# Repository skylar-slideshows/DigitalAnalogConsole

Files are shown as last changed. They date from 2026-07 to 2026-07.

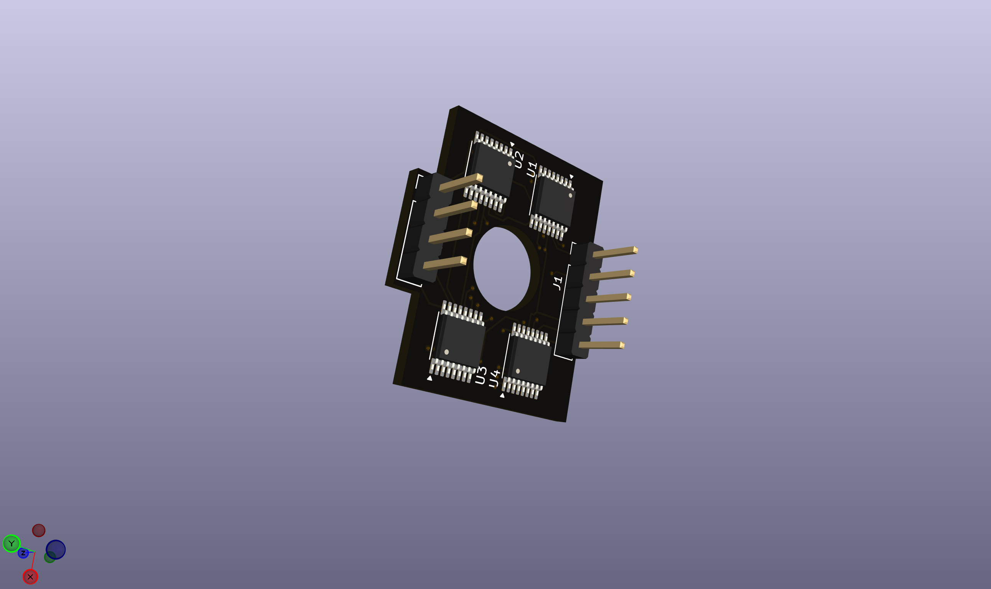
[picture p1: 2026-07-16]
PCB/led_ring_knob/3D2.png

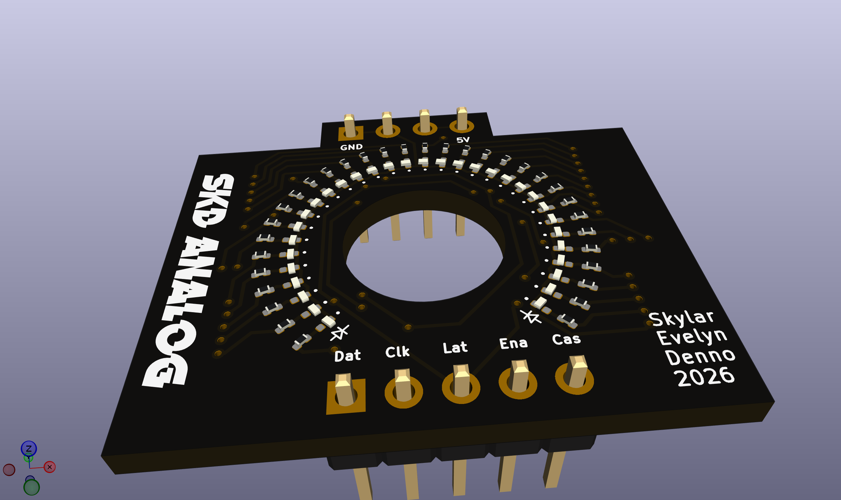
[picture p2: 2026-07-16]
PCB/led_ring_knob/3D1.png

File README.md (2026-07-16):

Skylar - Digital/Analog Music Mixing Console / Gear
A music mixing console with a fully analog audio signal path (no DSP), managed by a digital control system.

The problem to fix
Historically, music recording studios relied on analog audio processing equipment. While digital signal processing has largely replaced it, many professional audio engineers still prefer analog hardware for its perceived superior sound quality. However, analog equipment lacks instant recall, requiring engineers to manually reset knobs and controls between projects. Since these knobs control actual resistances/potentiometers in the signal path, they need to be physically moved to the right place. In today's fast-paced production environment, where multiple sessions may be completed in a single day, this process can be time-consuming and impractical.

Proposal
My proposal is to design a set of basic audio engineering analog sound processors (an EQualizer, a dynamic range compressor, and volume control) with a digital system that uses “voltage controlled resistors” to allow recall to be handled by a microprocessor, making it instant. Instead of having moving knobs that are physical resistors, the knobs will only be digital rotary encoders for which a microcontroller calculates their relative position. The microcontroller then uses a control voltage to set resistors in the analog signal path to the value that a real knob in that position would be, making the signal path exactly the same “to the audio.” This would also allow the microprocessor to automate and adjust many parameters at once, which is another limitation with analog audio equipment. These three basic devices can be combined into one digitally controlled, analog “channel strip” that handles one layer of audio in the mix of a song. Many of these channels side by side, with a master section that combines all the signals, makes an audio console. This kind of technology is present in some standalone pieces of audio equipment, as well as parts of some synthesizers, but it has never been done at such a large scale.

Technical explanation
The “knobs” in our device (actually rotary encoders), send a digital signal with their relative position. To “scan” all the digital encoder “knobs” positions’, a microcontroller can be multiplexed to them, cycling through looking at all the knobs’ data outputs several times per second, meaning a few GPIO pins can be used to interface with many knobs. 

The microcontroller then calculates the value that a real potentiometer (based on its value and taper - linear? Log? anti-log?) would have in that same positon.

To make voltage controlled resistors that actually supply this resistance in the analog audio path, there are many approaches. A FET transistor has a “triode” or “OHMIC” region between when it is on and off, of high resistance, which varies by its gate voltage. As long as we stay away from the very edges of this region, the behavior is approximately linear (moreso on JFETs - Junction Field Effect Transistors) making them suitable for audio.
Another way is with OTAs (operational transconductance amplifiers), which are voltage controlled current sources. Since resistors themselves turn voltage into current, OTAs are essentially like resistors for our purpose.

For a non-continuous controllable resistor, we can use a network of many resistors in series and parallel, with transistors (electronic switches) between them to connect them in various ways that can produce an equivalent resistance through the entire network of essentially any value we want. There are premade chips for this. (resistor ladders)

We need to make sure that however we control the components, it does not get in the way of making a highly linear (low harmonic distortion), high fidelity (flat frequency response between 20Hz and 20kHz) audio path - i.e. making a good sounding piece of equipment that doesn’t distort the sound.

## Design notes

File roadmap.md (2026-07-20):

Digital/Analog mixing console:

## More developed idea
- Clear goal/pathway to developing a finished project
- Covers areas of analog and digital electronics, some control systems, and software

## Room for development (what can 6 people spend several months on if this idea is already developed)

### Analog

#### Volume sliders
Voltage-controlled amplifiers: 
2x per channel, 32x total (16 channels)
  
#### Power Supply
+/-18V rails through a linear power supply for clean signal (min. ~15W) 
+3.3V clean reference for DACs in digital circuit (\~1W) 
+3.3V rail for digital electronics (\~20W) (isolated from clean ref. to prevent noise) 
+5V rail for LEDs 

#### Equalizer
State variable filter 
Control voltage comes from amplified DAC signal 
Op amp circuit to amplify DAC signal to control voltage for OTAs 

#### Pan
L/R VCAs for each channel 
Control voltage(s) come from DAC signal  

#### Toggle buttons (Mute/Solo)
Debounce circuit 
Button LED 
Software toggle to allow software control 

#### Insert points
Between each channel and the summing bus (pre- or post-fader option) 

#### Sends
Auxiliary busses

#### Master Section
Summing bus
AUX returns
Large screen
Master bus insert

#### Compressor

### Digital

#### Faders (motor-driven slide potentiometers)
Read by ADC on the chip 
Abstracted into something servo-like 
VCAs are controlled from software based on reading of faders 

#### EQ/Pan knobs
Rotary encoders 
LED ring 

#### Screens

### Software
(generally controlling all of the digital parts)

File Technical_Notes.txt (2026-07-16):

A mixing console is just a bunch of channels of signal processors, and a summing amplifier.
The three main tools audio engineers need on a mixing console are:
Volume (slider/fader to turn things up and down)
Equalizer (controllable frequency/bandwidth filters + summing with the original signal)
Dynamic compression (automatically turn loud parts of audio down but leave quiet audio untouched)

Volume/pan - will implement with VCA, controlled by a motorized fader being read by a microcontroller.

EQ - will implement with OTAs, voltage controllable "resistance" (current scaling) - fully parametric, can use OTAs to control freq, bw, and gain, see the analog design folder: EQ for spice sims.

Compression - will implement with VCA, the control voltage envelope generated by the microcontroller possibly. (otherwise will need OTAs for some params)

Digital control - microcontroller (STM32G474), rotary encoders (EC11), faders/slide potentiometers read by a ADC, screens, LEDs to show position of knobs (shift registers), outboard DACs (on SPI bus) to generate the control voltages.

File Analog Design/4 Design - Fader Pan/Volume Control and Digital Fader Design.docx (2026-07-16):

Volume Control and Digital Fader Design

We want a device that allows the volume of channels to be controlled with a slide potentiometer (Fader). Instead of a traditional analog design with the audio signal running through the fader’s resistance strip itself, we use a microcontroller to read the position of the fader through its resistance. That microcontroller then addresses the VCA with a control voltage that produces the specified gain/atten.

This has the benefit of being instantly recallable and able to be saved and automated digitally.

Microcontroller for each bucket of 8 faders = RP2040. $1 per bucket

The ALPS RSA0N11M9 fader was chosen. It is motorized, touch sensitive, 10kOhm linear taper. 100mm long throw length. $26x8 = $208 per bucket

THAT 2181 is chosen for VCA. $6.5*16 = $104 per bucket

For line input receiver – TI INA2134 (stereo). $6x8 = $48 per bucket

Separate analog and [digital+controllers(pots,faders)] boards. They sit on top of each other (analog bottom)

PINS: (3+32+16)

Analog GND

+18V Power

-18V Power

VCA C1L

VCA C1R

VCA C2L

…

VCA C8R

Fader1 Voltage

Fader2 Voltage

…

Fader8 Voltage

Pan1 Voltage

Pan2Voltage

…

Pan8Voltage

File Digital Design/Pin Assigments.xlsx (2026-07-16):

FN | DESC | PROTO | PIN # | LABEL | CONN | STM32G4(74RET6)
KNOBS | 8 x MCP23017 - 40 rotary encoders | I2C 1 | PB8 | KNOB_I2C1_CL
 |  |  | PB7 | KNOB_I2C1_DA
BUTTONS | 1 x MCP23017 - 16 Buttons | I2C 2 | PC4 | BTNS_I2C2_CL
 |  |  | PF0 | BTNS_I2C2_DA
MASTER | Comm to master controller | I2C 3 | PC8 | MASTER_I2C3_CL
 |  |  | PC9 | MASTER_I2C3_DA
CV | Output Control Voltage to devices DAC80508M | SPI 1 Transmit ONLY | PA5 | CV_SPI1_CL
 |  |  | PA7 | CV_SPI1_MOSI
DISP_1_2 | Displays 1 and 2 | SPI 2 Transmit ONLY | PF1 | DISP12_SPI2_CL
 |  |  | PB15 | DISP12_SPI2_MOSI
DISP_3_4 | Displays 3 and 4 | SPI 3 Transmit ONLY | PC10 | DISP34_SPI3_CL
 |  |  | PB5 | DISP34_SPI3_MOSI
LEDS | 74HCT595 Clocks | GPIO | PC13 | LED_CL
 | 74HCT595 Data | GPIO | PC2 | LED_DA
 | 74HCT595 Latches | GPIO | PC3 | LED_LATCH
 | 74HCT595 Output enable (brightness) | TIM1 PWM 2khz ch1 | PC0 | LED_BRIGHT_PWM
DISP BACKLIGHT | Display backlight control | TIM1 PWM 2khz ch2 | PC1 | DISP_BRIGHT_PWM
RESET | Active low (built in pull up) |  | PG10 | NRST
PRGM | Programming firmware to the chip | SWD | PA13 | SWDIO
 |  |  | PA14 | SWCLK
VSS_Analog | Clean gnd ref for adcs (analog gnd plane) |  | VSSA | VSSA
VDD_Analog | Clean 3v3 ref for adcs (filter 3v3B23:B33 |  | VDDA | VDDA
V_Battery | Tie to 3v3 VCC regular (no battery) |  | VBAT | VBAT
V_reference + | Tie to clean 3v3 same as VDDA |  | VREF+ | VREF+
FADER | Read position of slide pots thru built in adcs | ADC 1 CH 1-4 | PA0 | FADER1_ADC
 |  |  | PA1 | FADER2_ADC
 |  |  | PA2 | FADER3_ADC
 |  |  | PA3 | FADER4_ADC
FADER TOUCH | Sense if faders are being touched (capacitive sampling TTP224) | GPIO INPUT | PB11 | FADER1_TOUCH
 |  |  | PB12 | FADER2_TOUCH
 |  |  | PB13 | FADER3_TOUCH
 |  |  | PB14 | FADER4_TOUCH
FADER MOTOR | Fader motor controller with PWM H bridges (DRV8833 x2) | TIM2 PWM 24khz ch1/2 | PA15 | FADER1_MOTOR1
 |  |  | PB3 | FADER1_MOTOR2
 |  | TIM3 PWM 24khz ch1/2 | PA6 | FADER2_MOTOR1
 |  |  | PA4 | FADER2_MOTOR2
 |  | TIM4 PWM 24khz ch1/2 | PA11 | FADER3_MOTOR1
 |  |  | PA12 | FADER3_MOTOR2
 |  | TIM5 PWM 24khz ch1/2 | PB2 | FADER4_MOTOR1
 |  |  | PC12 | FADER4_MOTOR2

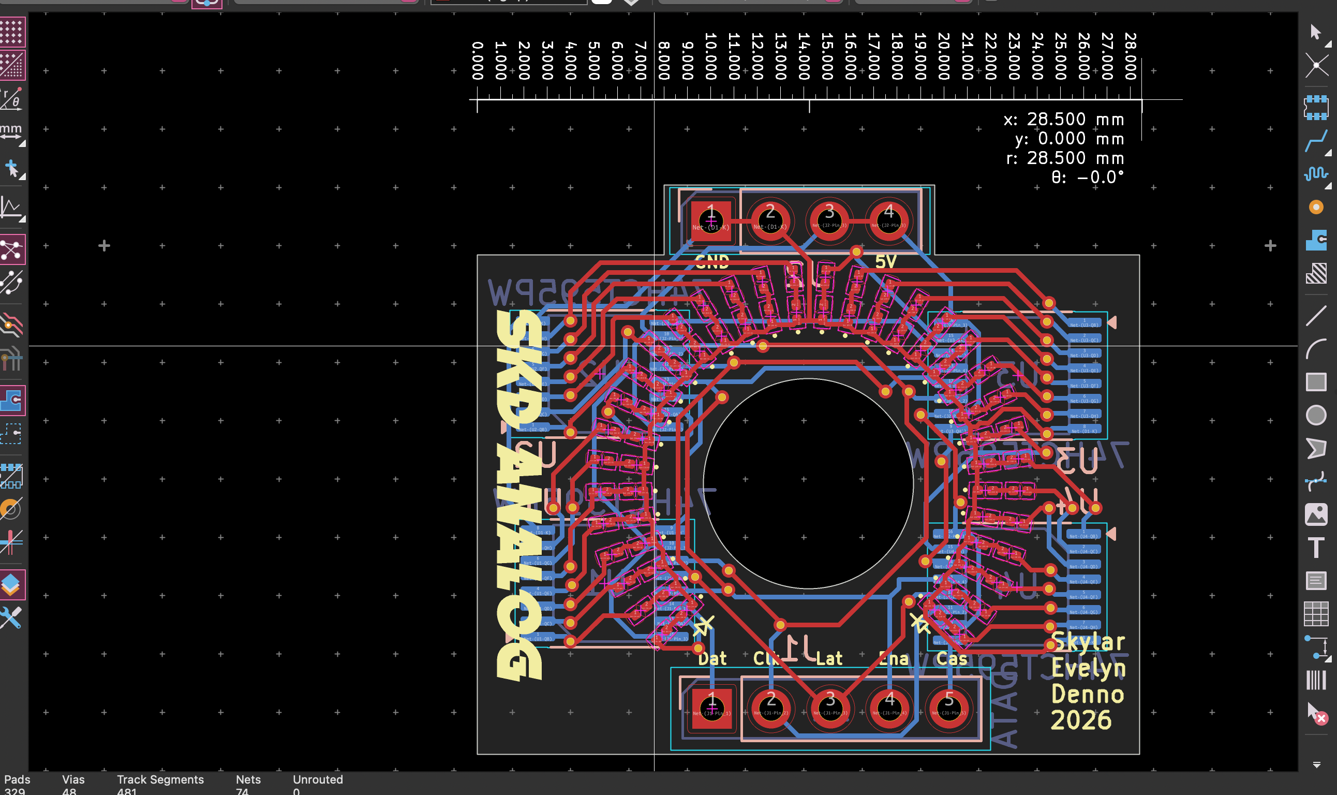
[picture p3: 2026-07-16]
PCB/led_ring_knob/layout.png

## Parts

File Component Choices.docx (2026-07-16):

DIGITAL

Controller – STM32G474

Addtl ADC - ADS1115

Addtl DAC – DAC80508M

?Use? I2C Multiplexer - TCA9548A

Op Amp Control Sigs - TL074

PHYSICAL

Fader – Alps RSA0N Slide 100mm Motorized, Touch sensitive (Clones)

Rotary Encoder – EC11 with switch (press knob), cap = sifam 11.5mm

LED Shift Register - 74HCT595 (4x per knob)

Button –

Laser Cutter – xTool M2

ANALOG

Op Amp – NE5532

Op Amp (Hifi) – OPA 2134

Line In – INA 2137

OTA – LM13700

VCA – THAT 2180B

Signal Switch - ADG1404

VU Meter – LM3916

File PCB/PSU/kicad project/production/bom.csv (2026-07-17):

Designator | Footprint | Quantity | Value | LCSC Part #
C1, C11, C12, C2, C3, C4 | CP_Radial_D18.0mm_P7.50mm | 6 | 4700u
C10, C14, C9 | 1206 | 3 | 100n
C13, C7, C8 | C_Rect_L24.0mm_W12.6mm_P22.50mm_MKT | 3 | 10u
C15 | 1206 | 1 | 10n
C16, C18, C20, C22 | CP_Radial_D12.5mm_P5.00mm | 4 | 1000u
C17, C19, C21, C23 | CP_Radial_D10.0mm_P5.00mm | 4 | 470u
C5, C6 | CP_Elec_6.3x5.4 | 2 | 10u
D1, D2, D3, D4 | D_DO-201AD_P15.24mm_Horizontal | 4 | 1N5404
D10, D11, D12, D13, D14, D15 | LED_Rectangular_W3.9mm_H1.8mm | 6 | LED
D5, D6 | Diode_Bridge_32.0x5.6x17.0mm_P10.0mm_P7.5mm | 2 | GBJ2510
D7, D8, D9 | D_SOD-123 | 3 | 1N4148
HS1, HS2, HS3 | HSINK_HSE-B20380-040H | 3 | Heatsink
J10 | TerminalBlock_Phoenix_MKDS-1,5-2-5.08_1x02_P5.08mm_Horizontal | 1 | SMPS_IN
J2 | TerminalBlock_Phoenix_MKDS-1,5-4-5.08_1x04_P5.08mm_Horizontal | 1 | OUT_ANLG
J3 | TerminalBlock_Phoenix_MKDS-1,5-2-5.08_1x02_P5.08mm_Horizontal | 1 | MAINS_IN
J4 | TerminalBlock_Phoenix_MKDS-1,5-4-5.08_1x04_P5.08mm_Horizontal | 1 | Screw_Terminal_01x04
J5 | TerminalBlock_Phoenix_MKDS-1,5-4_1x04_P5.00mm_Horizontal | 1 | T1_SEC
J6 | PinHeader_1x03_P2.54mm_Vertical | 1 | GND_LIFT
J7 | PinHeader_1x02_P2.54mm_Vertical | 1 | FAN1_12V
J8 | PinHeader_1x02_P2.54mm_Vertical | 1 | FAN2_12V
J9 | TerminalBlock_Phoenix_MKDS-1,5-4-5.08_1x04_P5.08mm_Horizontal | 1 | OUT_DIGI
L1, L2, L3, L4 | L_Vishay_IHLP-5050 | 4 | 4.7u
R1, R2, R3 | R_Axial_DIN0414_L11.9mm_D4.5mm_P20.32mm_Horizontal | 3 | 1k
R10, R9 | 1206 | 2 | 1.5k
R11, R12 | 1206 | 2 | 100
R13 | 1206 | 1 | 330
R14 | 1206 | 1 | 820
R15 | 1206 | 1 | 56k
R16, R17, R18, R19 | R_Axial_DIN0207_L6.3mm_D2.5mm_P10.16mm_Horizontal | 4 | 0.33R
R4 | 0805 | 1 | 10
R5, R6 | 1206 | 2 | 4.7k
R7, R8 | 1206 | 2 | 360
SW2 | SW_V80214MS02Q | 1 | V80212MS02Q
TH1 | C_Disc_D12.5mm_W5.0mm_P7.50mm | 1 | MF72-010D9
TR2 | AMGIS L01-63XX | 1 | Amgis L01-6320
U1 | TO-220-3_Vertical | 1 | LM317AT/NOPB
U2 | TO-220-3_Vertical | 1 | LM337T/NOPB
U3 | TO-220-3_Vertical | 1 | LD1117V33C
U5 | Converter_DCDC_XP_POWER_JTDxxxxxxx_THT | 1 | 3v3 Mornsun URB4803LD-20WR3
U6 | MeanWell NID100 | 1 | MeanWell NID-100-5
U7 | Converter_DCDC_XP_POWER_JTDxxxxxxx_THT | 1 | 12v Mornsun URB2412LD-30WR3

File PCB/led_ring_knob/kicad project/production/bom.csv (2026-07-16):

Designator | Footprint | Quantity | Value | LCSC Part #
D1, D10, D11, D12, D13, D14, D15, D16, D17, D18, D19, D2, D20, D21, D22, D23, D24, D25, D26, D27, D28, D29, D3, D30, D31, D32, D4, D5, D6, D7, D8, D9 | 0201 | 32 | CSP0603AN101-WP30300563001-3T
J1 | PinHeader_1x05_P2.54mm_Vertical | 1 | DATA
J2 | PinHeader_1x04_P2.54mm_Vertical | 1 | POW
R1, R10, R11, R12, R13, R14, R15, R16, R17, R18, R19, R2, R20, R21, R22, R23, R24, R25, R26, R27, R28, R29, R3, R30, R31, R32, R4, R5, R6, R7, R8, R9 | 0201 | 32 | 330
U1, U2, U3, U4 | TSSOP-16_4.4x5mm_P0.65mm | 4 | 74HCT595PW

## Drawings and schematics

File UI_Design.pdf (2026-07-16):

## SEND

## Aux 1 (press enable)

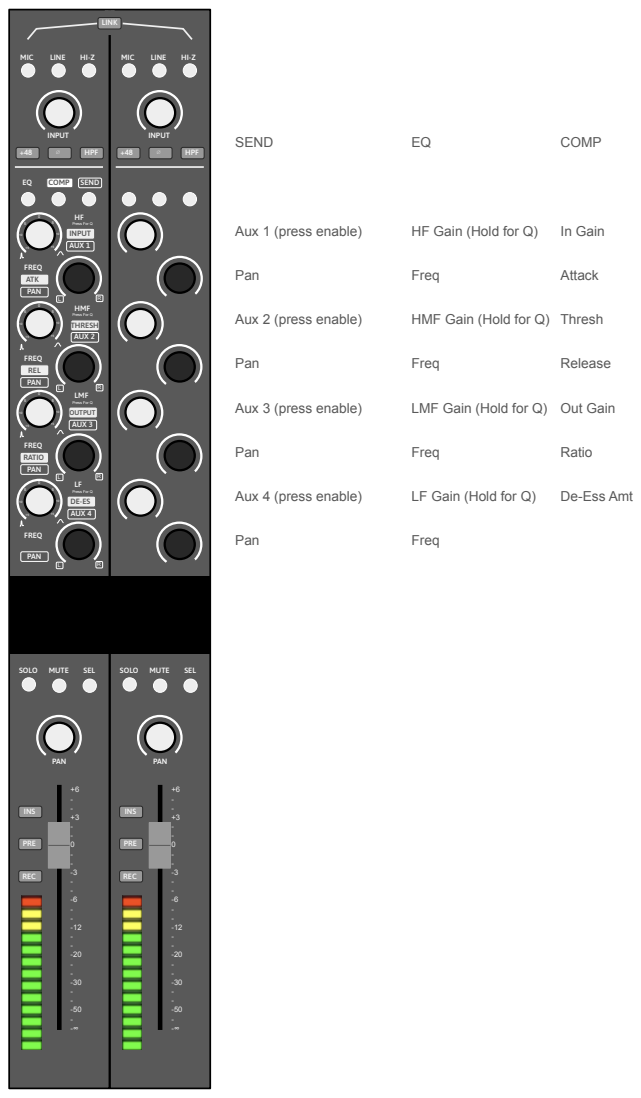
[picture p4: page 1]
SOLO; MUTE; SEL; PAN; COMP; SEND; MIC; LINE; HPF; INS; PRE; REC; LINK; INPUT; Pan; Freq; In Gain; Attack; Thresh; Release; Out Gain; Ratio; FREQ; Press For Q; HMF; LMF; ATK; THRESH; REL; OUTPUT; RATIO; AUX 1; AUX 2; AUX 3; AUX 4

HF Gain (Hold for Q)

Aux 2 (press enable)

HMF Gain (Hold for Q)

Aux 3 (press enable)

LMF Gain (Hold for Q)

LF Gain (Hold for Q)

Aux 4 (press enable)

De-Ess Amt

## AUX INPUTS

1 2

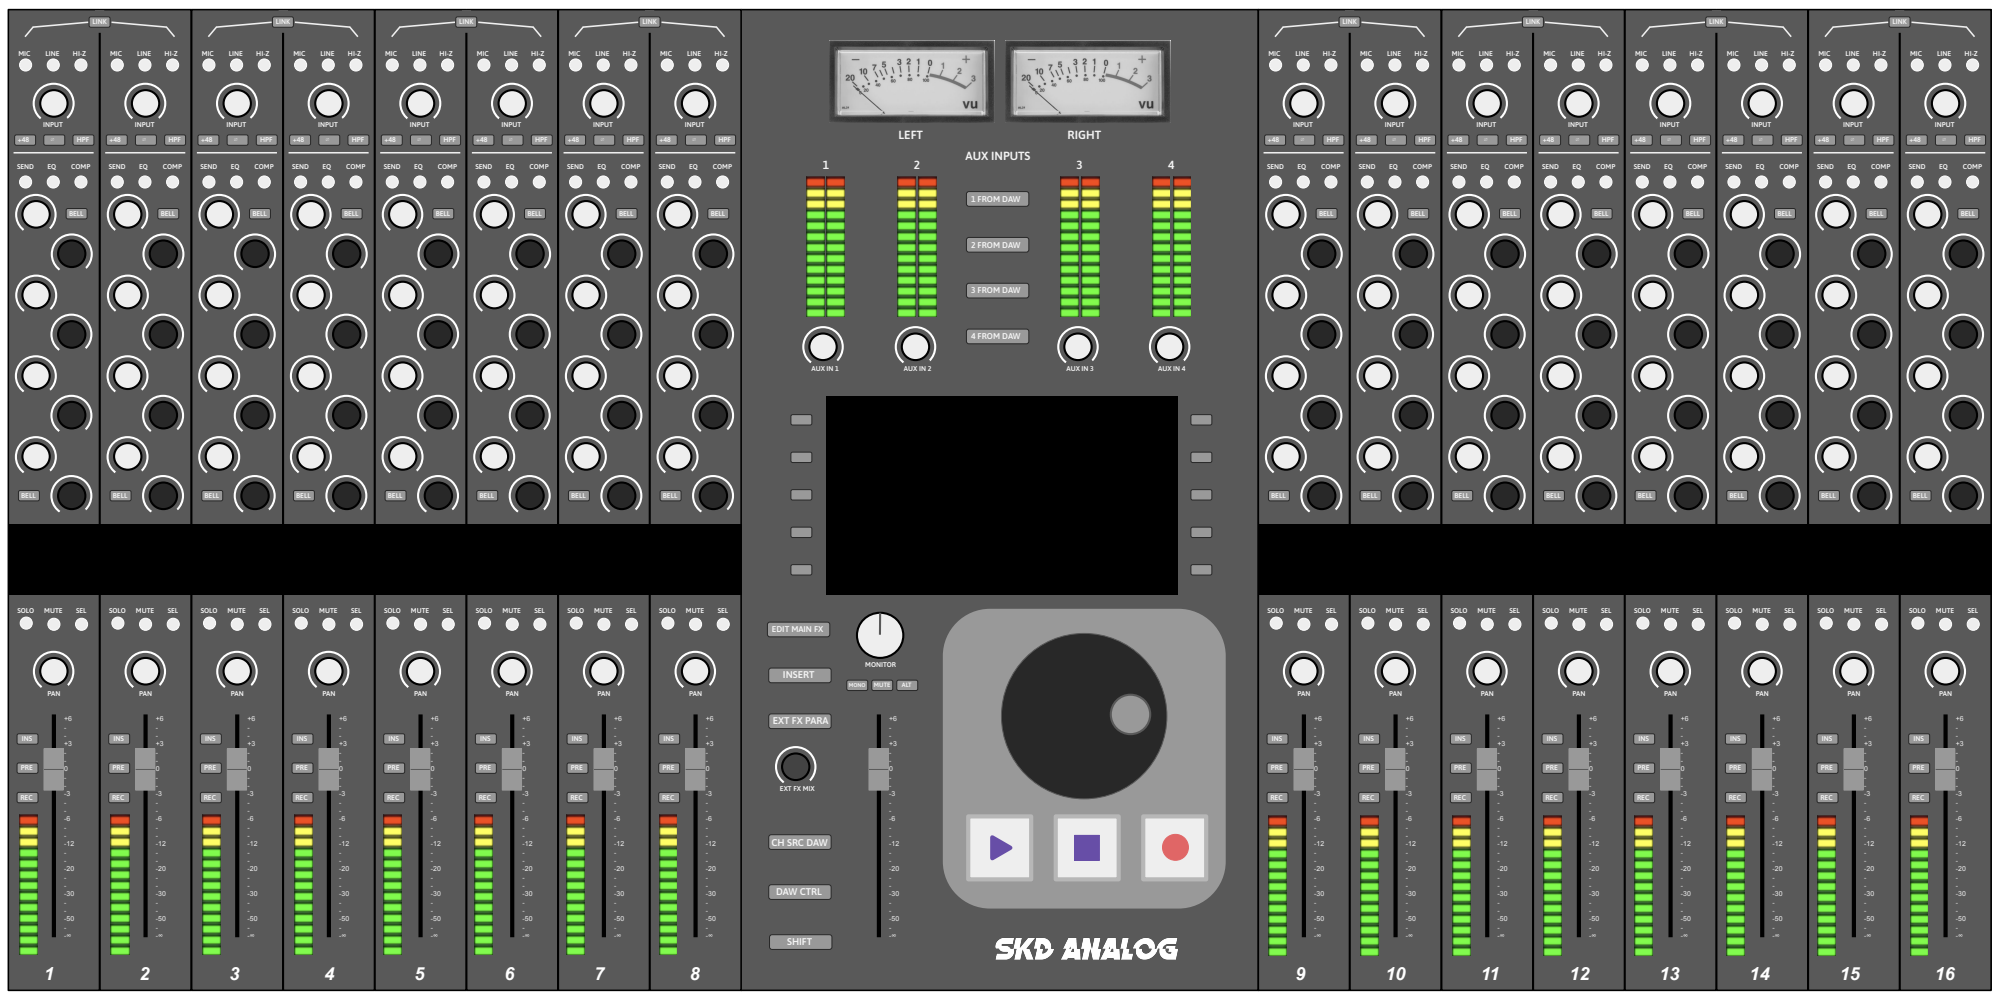
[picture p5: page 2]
SOLO; MUTE; SEL; PAN; SEND; COMP; MIC; LINE; BELL; HPF; INS; PRE; REC; LINK; INPUT; AUX IN 1; AUX IN 2; DAW CTRL; SHIFT; 1 FROM DAW; 2 FROM DAW; 3 FROM DAW; 4 FROM DAW; AUX IN 3; AUX IN 4; LEFT; RIGHT; INSERT; MONITOR; MONO; ALT

EDIT MAIN FX

EXT FX PARA

EXT FX MIX

CH SRC DAW

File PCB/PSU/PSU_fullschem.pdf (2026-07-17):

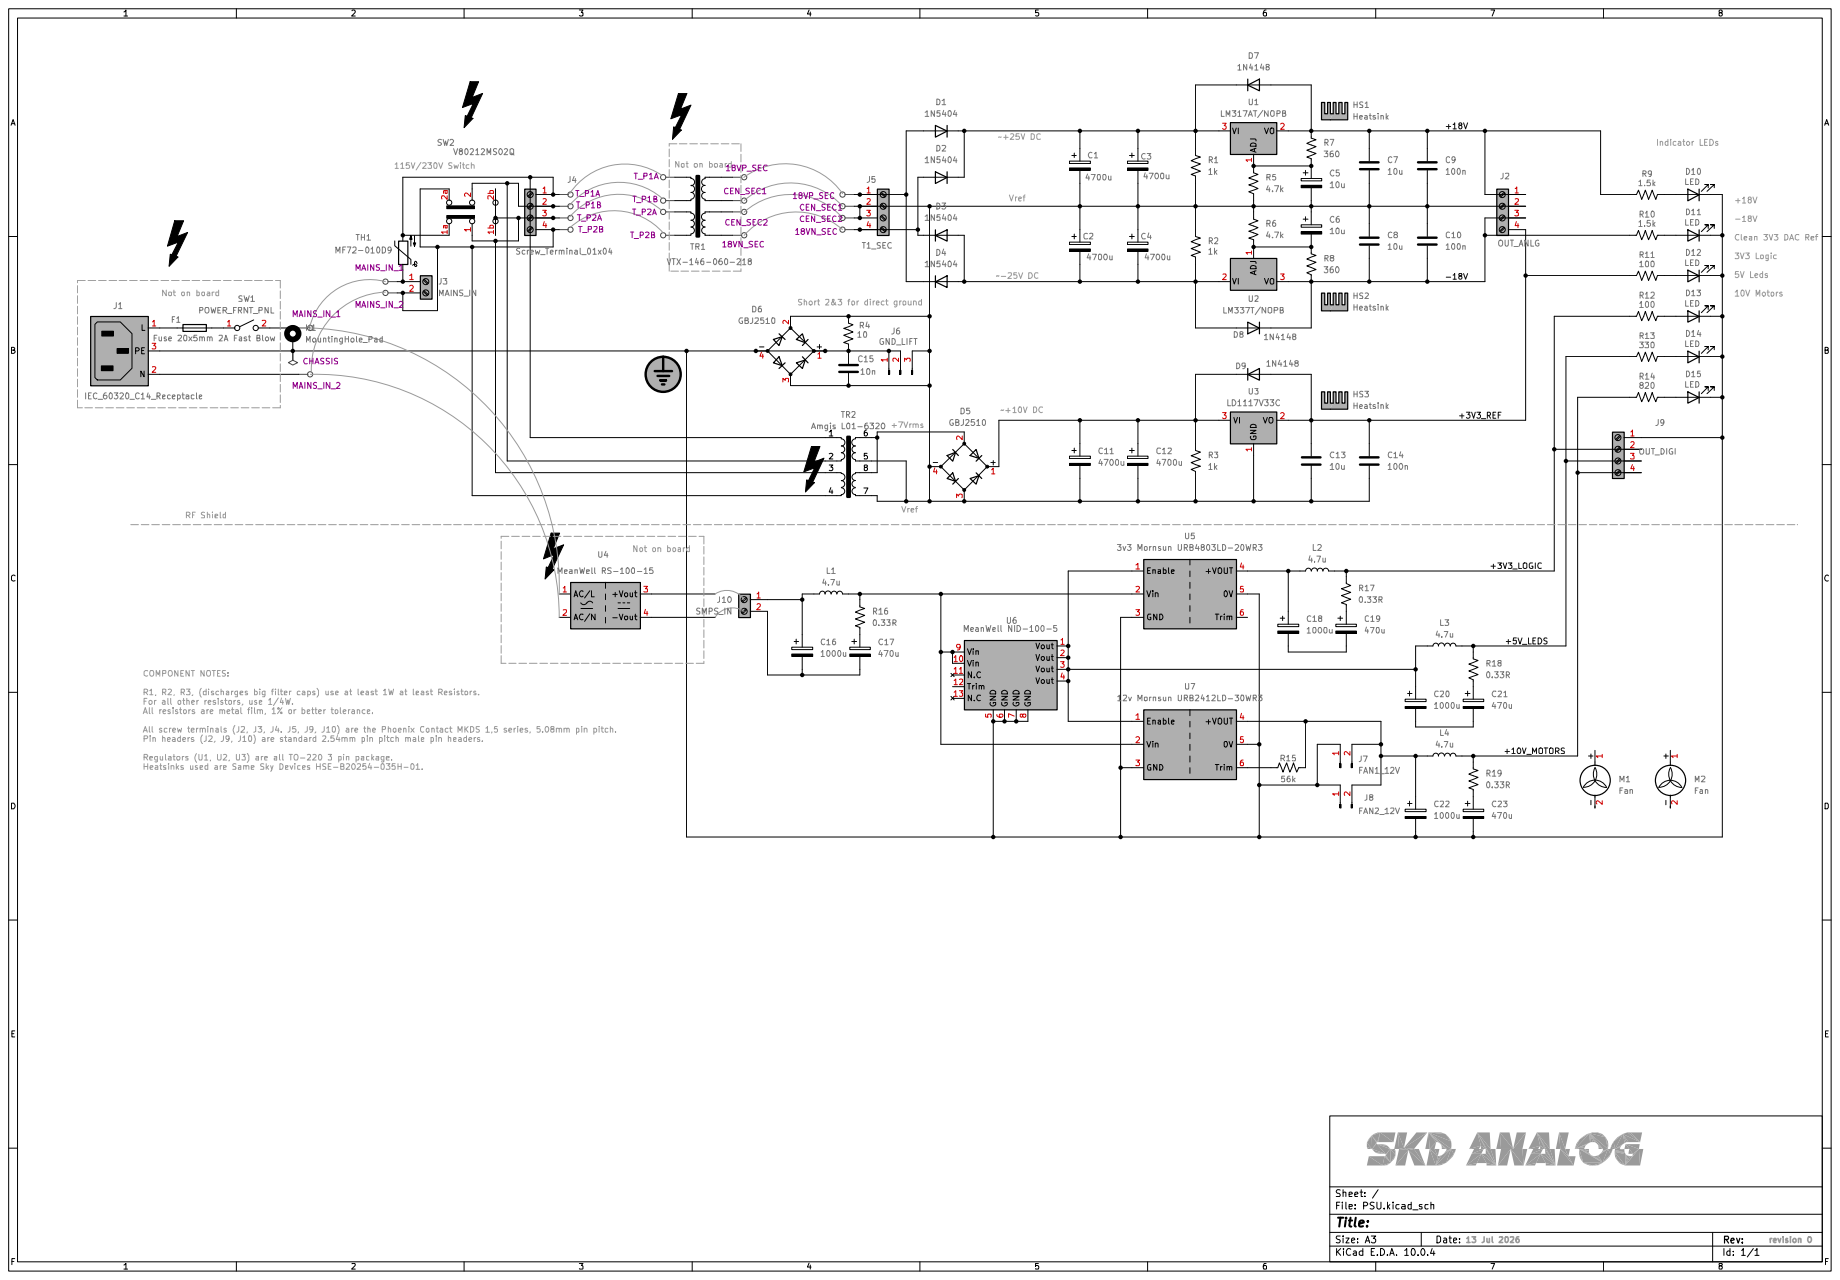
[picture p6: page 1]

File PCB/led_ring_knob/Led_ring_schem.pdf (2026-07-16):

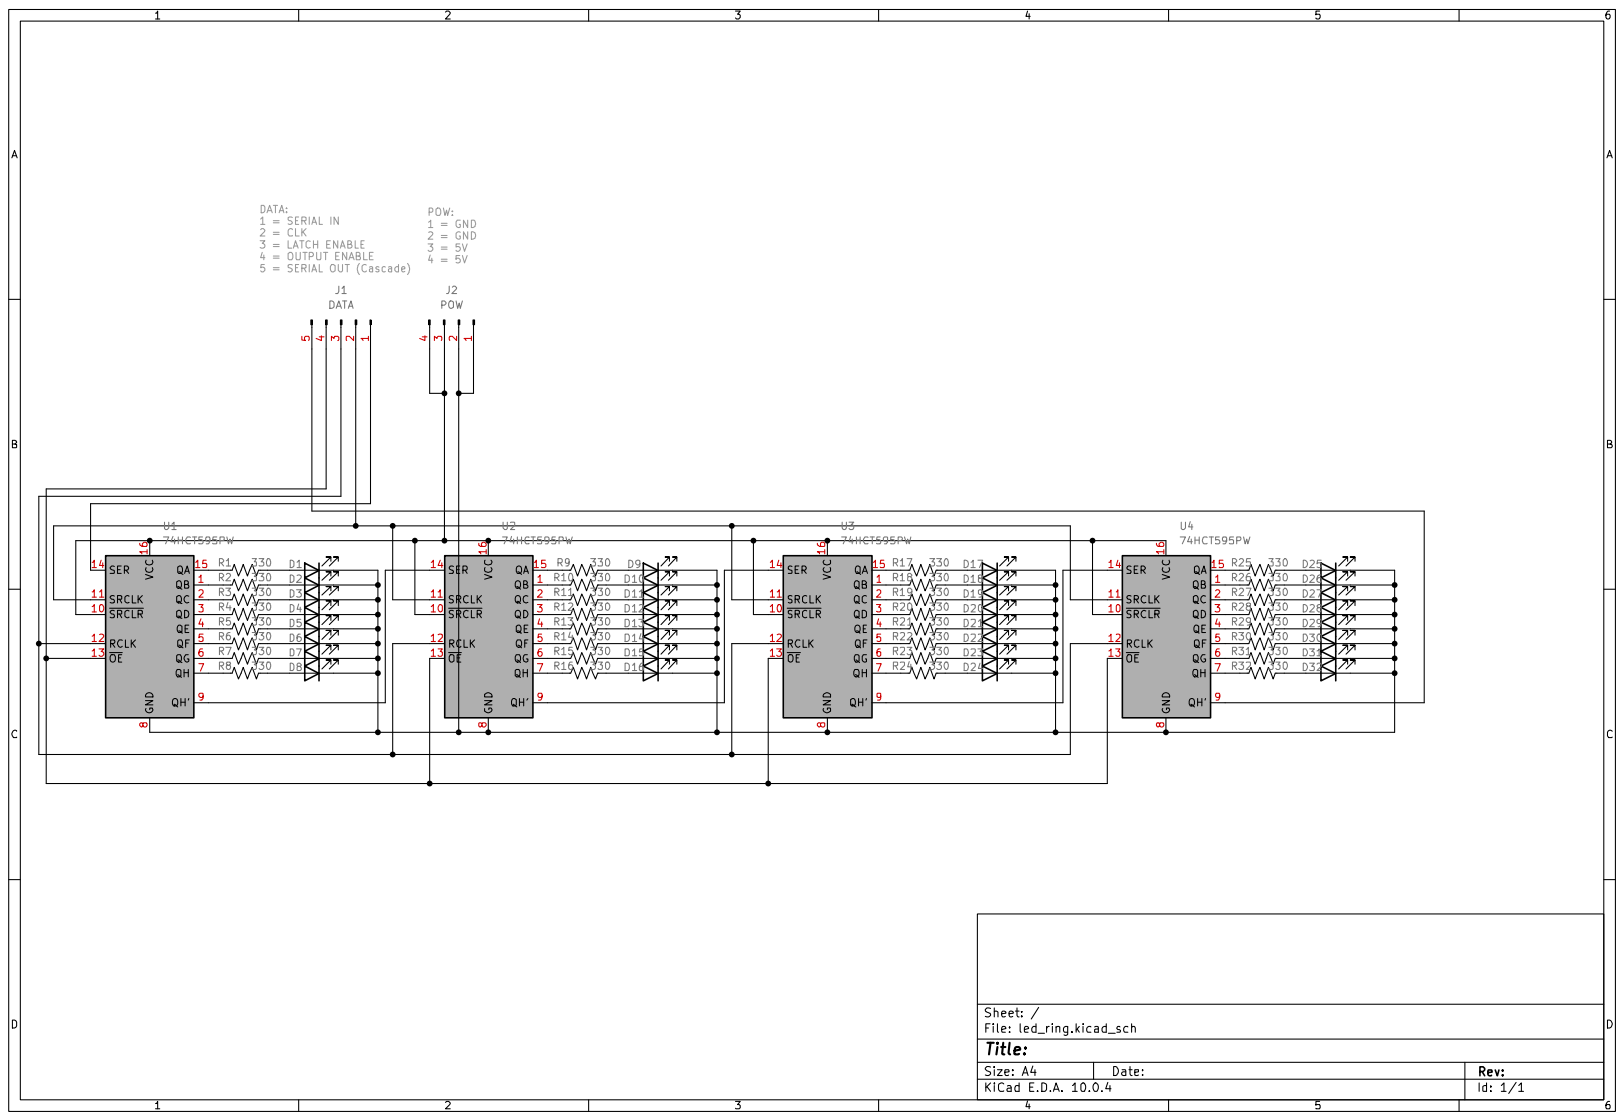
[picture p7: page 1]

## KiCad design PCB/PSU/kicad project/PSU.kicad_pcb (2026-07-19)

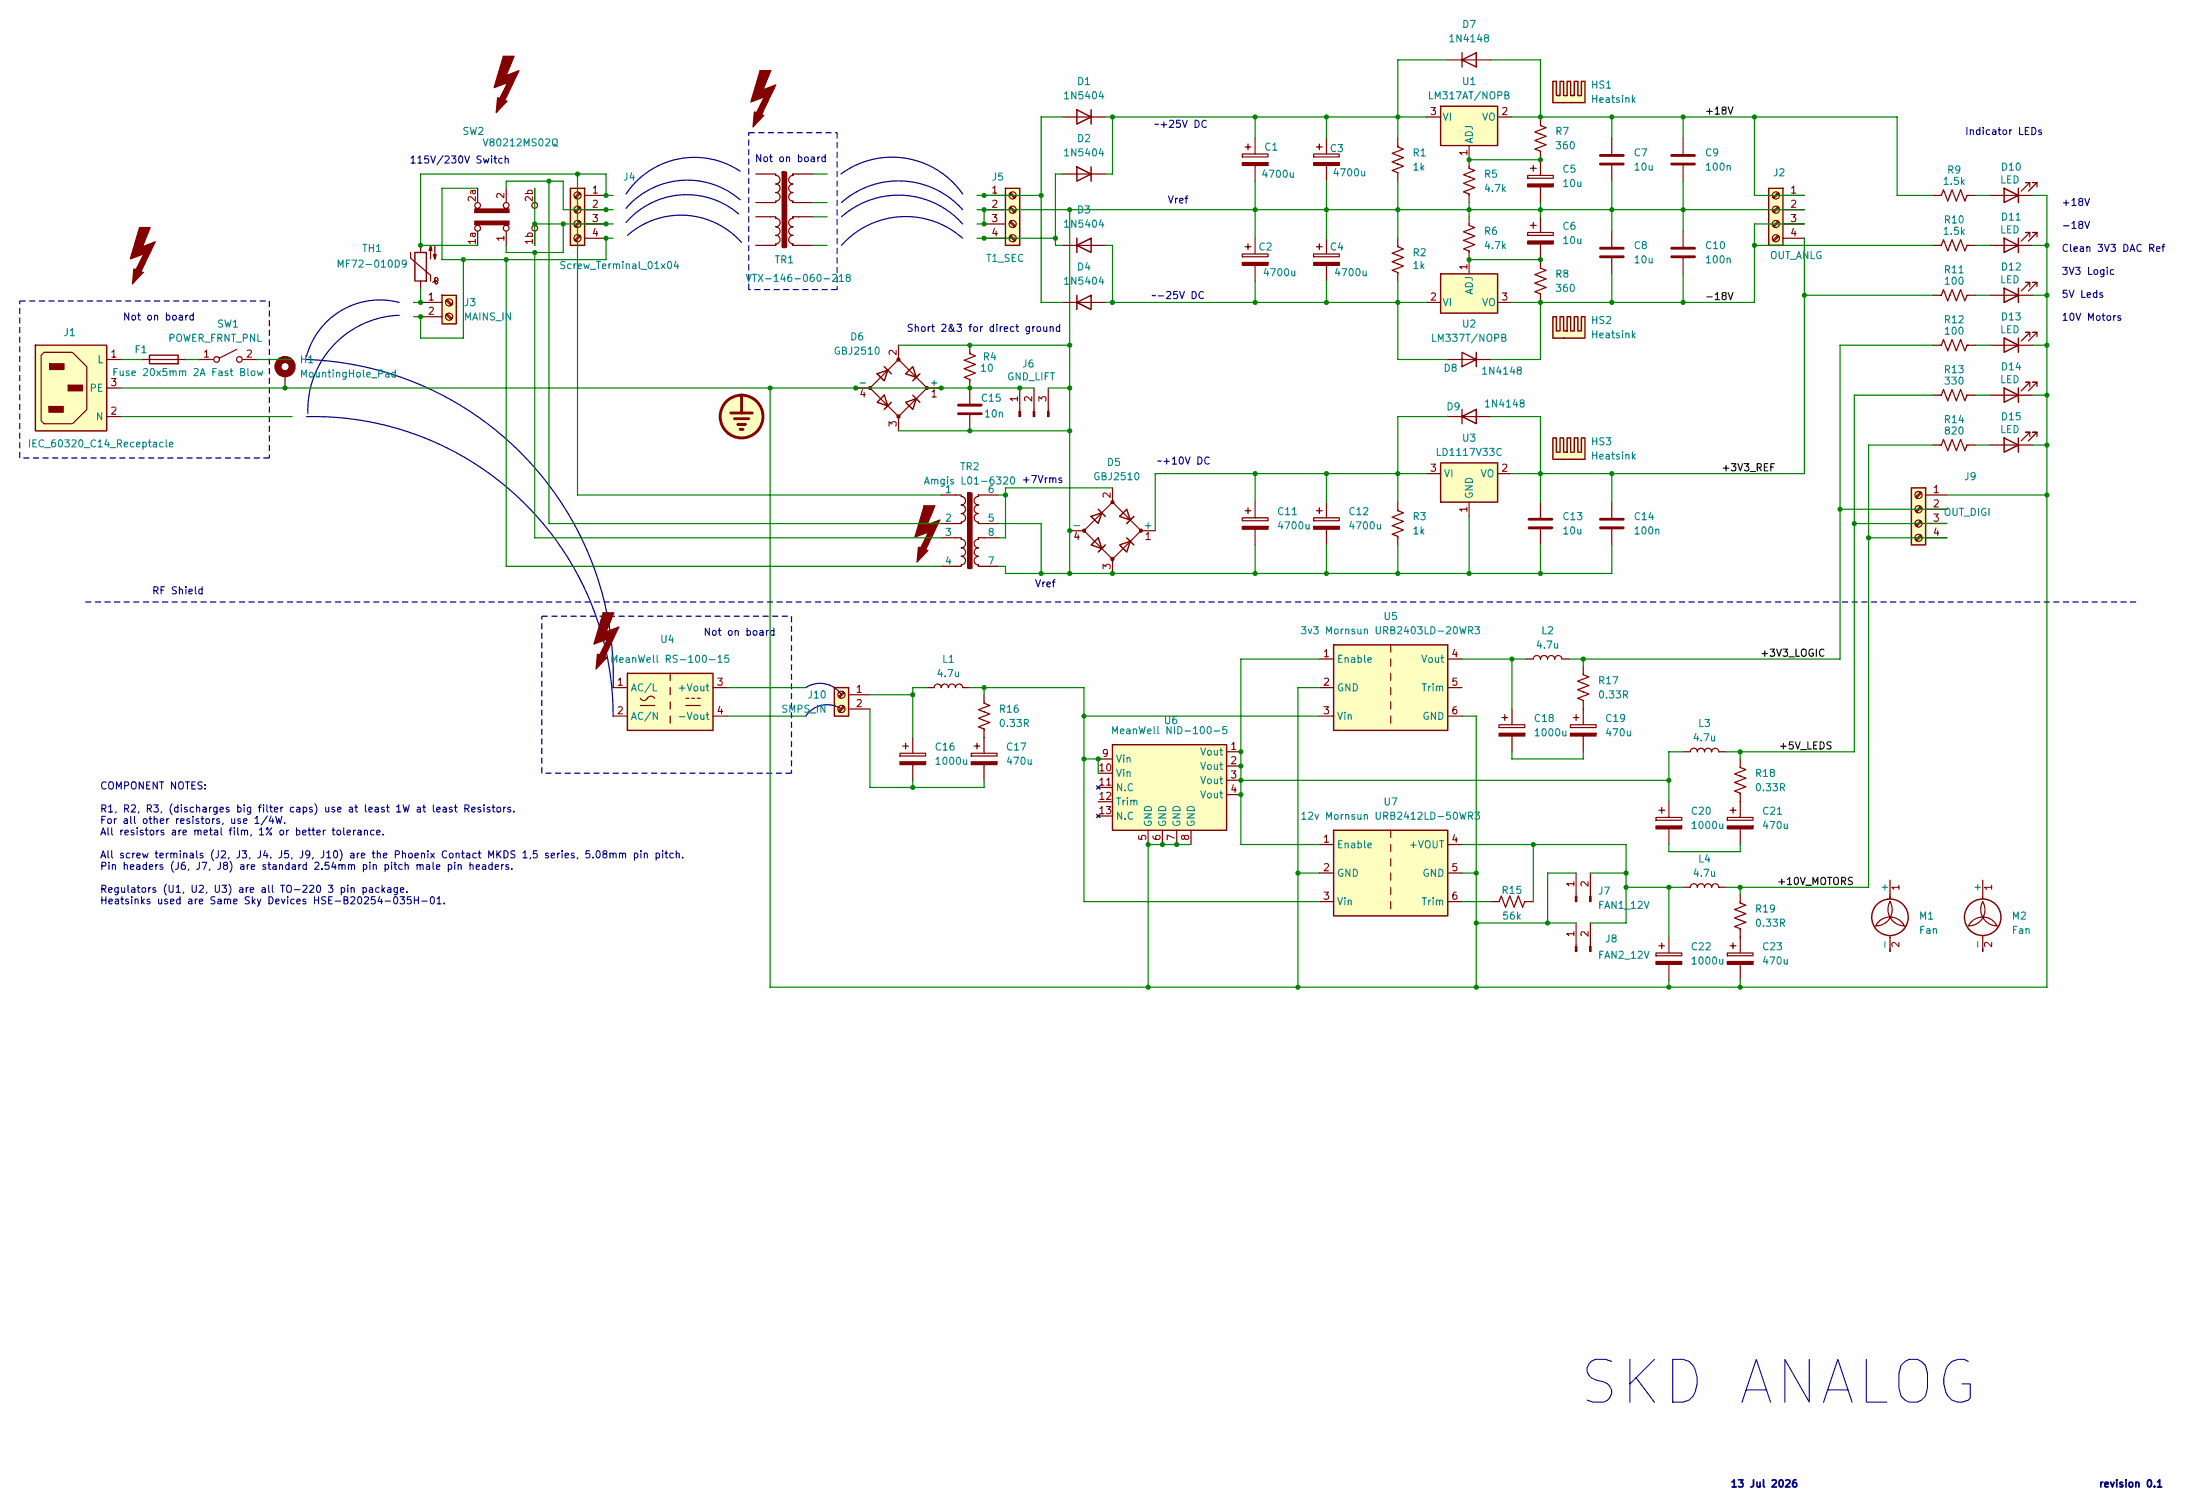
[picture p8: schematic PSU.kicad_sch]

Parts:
C1, C2, C3, C4, C11, C12: 4700u; CP_Radial_D18.0mm_P7.50mm; LCSC C443892
C5, C6: 10u; CP_Elec_6.3x5.4; LCSC C14162
C7, C8, C13: 10u; C_Rect_L24.0mm_W12.6mm_P22.50mm_MKT; LCSC C328801
C9, C10, C14: 100n; C_1206_3216Metric; LCSC C1945
C15: 10n; C_1206_3216Metric; LCSC C55077
C16, C18, C20, C22: 1000u; CP_Radial_D12.5mm_P5.00mm; LCSC C122661
C17, C19, C21, C23: 470u; CP_Radial_D10.0mm_P5.00mm; LCSC C116237
D1, D2, D3, D4: 1N5404; D_DO-201AD_P15.24mm_Horizontal; LCSC C222547
D5, D6: GBJ2510; Diode_Bridge_32.0x5.6x17.0mm_P10.0mm_P7.5mm; LCSC C27523
D7, D8, D9: 1N4148; D_SOD-123; LCSC C2099
D10, D11, D12, D13, D14, D15: LED; LED_Rectangular_W3.9mm_H1.8mm
F1: Fuse 20x5mm 2A Fast Blow
H1: MountingHole_Pad; MountingHole_3.2mm_M3_Pad_TopBottom
HS1, HS2, HS3: Heatsink; HSINK_HSE-B20380-040H
J1: IEC_60320_C14_Receptacle
J2: OUT_ANLG; TerminalBlock_Phoenix_MKDS-1,5-4-5.08_1x04_P5.08mm_Horizont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; LCSC C5443561
J3: MAINS_IN; TerminalBlock_Phoenix_MKDS-1,5-2-5.08_1x02_P5.08mm_Horizont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; LCSC C5443539
J4: Screw_Terminal_01x04; TerminalBlock_Phoenix_MKDS-1,5-4-5.08_1x04_P5.08mm_Horizont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; LCSC C5443561
J5: T1_SEC; TerminalBlock_Phoenix_MKDS-1,5-4_1x04_P5.00mm_Horizontal; LCSC C5443561
J6: GND_LIFT; PinHeader_1x03_P2.54mm_Vertical; LCSC C5360899
J7: FAN1_12V; PinHeader_1x02_P2.54mm_Vertical; LCSC C5360898
J8: FAN2_12V; PinHeader_1x02_P2.54mm_Vertical; LCSC C5360898
J9: OUT_DIGI; TerminalBlock_Phoenix_MKDS-1,5-4-5.08_1x04_P5.08mm_Horizont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; LCSC C5443561
J10: SMPS_IN; TerminalBlock_Phoenix_MKDS-1,5-2-5.08_1x02_P5.08mm_Horizont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; LCSC C5443539
L1, L2, L3, L4: 4.7u; L_Vishay_IHLP-5050; LCSC C845092
M1, M2: Fan
R1, R2, R3: 1k; R_Axial_DIN0414_L11.9mm_D4.5mm_P20.32mm_Horizontal; LCSC C5200473
R4: 10; R_0805_2012Metric; LCSC C340448
R5, R6: 4.7k; R_1206_3216Metric; LCSC C702850
R7, R8: 360; R_1206_3216Metric; LCSC C497314
R9, R10: 1.5k; R_1206_3216Metric; LCSC C26030
R11, R12: 100; R_1206_3216Metric; LCSC C49286685
R13: 330; R_1206_3216Metric; LCSC C49330184
R14: 820; R_1206_3216Metric; LCSC C17984
R15: 56k; R_1206_3216Metric; LCSC C4513
R16, R17, R18, R19: 0.33R; R_Axial_DIN0207_L6.3mm_D2.5mm_P10.16mm_Horizontal; LCSC C119970
SW1: POWER_FRNT_PNL
SW2: V80212MS02Q; SW_V80214MS02Q
TH1: MF72-010D9; C_Disc_D12.5mm_W5.0mm_P7.50mm
TR1: VTX-146-060-218
TR2: Amgis L01-6320; AMGIS L01-63XX
U1: LM317AT/NOPB; TO-220-3_Vertical; LCSC C94659
U2: LM337T/NOPB; TO-220-3_Vertical; LCSC C2869423
U3: LD1117V33C; TO-220-3_Vertical; LCSC C672117
U4: MeanWell RS-100-15
U5: 3v3 Mornsun URB2403LD-20WR3; Converter_DCDC_XP_POWER_JTDxxxxxxx_THT
U6: MeanWell NID-100-5; MeanWell NID100
U7: 12v Mornsun URB2412LD-50WR3; urb 50w dc-dc

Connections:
/+3V3_LOGIC: J9.2, L2.2, R12.1, R17.1
/+3V3_REF: C13.1, C14.1, D9.2 (A), J2.4, R11.1, U3.2 (VO)
/+5V_LEDS: J9.3, L3.2, R13.1, R18.1
/+10V_MOTORS: J9.4, L4.2, R14.1, R19.1
/+18V: C7.1, C9.1, D7.2 (A), J2.1, R7.1, R9.1, U1.2 (VO)
/-18V: C8.2, C10.2, D8.1 (K), J2.3, R8.2, R10.1, U2.3 (VO)
unnamed: C17.1, R16.2
unnamed: C18.2, C19.2
unnamed: C19.1, R17.2
unnamed: C20.2, C21.2
unnamed: C21.1, R18.2
unnamed: C23.1, R19.2
unnamed: D1.2 (A), D4.1 (K), J5.1
unnamed: C1.1, C3.1, D1.1 (K), D2.1 (K), D7.1 (K), R1.1, U1.3 (VI)
unnamed: D2.2 (A), D3.1 (K), J5.4
unnamed: C2.2, C4.2, D3.2 (A), D4.2 (A), D8.2 (A), R2.2, U2.2 (VI)
unnamed: C11.1, C12.1, D5.1 (+), D9.1 (K), R3.1, U3.3 (VI)
unnamed: C1.2, C2.1, C3.2, C4.1, C5.2, C6.1, C7.2, C8.1, C9.2, C10.1, C11.2, C12.2, C13.2, C14.2, C15.1, D5.3, D5.4 (-), D6.2, D6.3, J2.2, J5.2, J5.3, J6.3, R1.2, R2.1, R3.2, R4.2, R5.2, R6.1, TR2.5, TR2.7, U3.1 (GND)
unnamed: D5.2, TR2.6, TR2.8
unnamed: D10.2 (A), R9.2
unnamed: C15.2, C22.2, C23.2, D6.1 (+), D6.4 (-), D10.1 (K), D11.1 (K), D12.1 (K), D13.1 (K), D14.1 (K), D15.1 (K), H1.1 (1_1), J1.3 (PE), J6.1, J6.2, J7.1, J8.1, J9.1, R4.1, U5.2 (GND), U5.6 (GND), U6.5 (GND), U6.6 (GND), U6.7 (GND), U6.8 (GND), U7.2 (GND), U7.5 (GND)
unnamed: D11.2 (A), R10.2
unnamed: D12.2 (A), R11.2
unnamed: D13.2 (A), R12.2
unnamed: D14.2 (A), R13.2
unnamed: D15.2 (A), R14.2
unnamed: F1.1, J1.1 (L)
unnamed: F1.2, SW1.1 (A)
unnamed: J3.1, TH1.1
unnamed: J3.2, J4.4, SW2.2a, TR2.4
unnamed: J4.1, SW2.1a, TH1.2, TR2.1
unnamed: J4.2, SW2.2, TR2.2
unnamed: J4.3, SW2.1, SW2.1b, SW2.2b, TR2.3
unnamed: C22.1, J7.2, J8.2, L4.1, R15.2, U7.4 (+VOUT)
unnamed: C16.1, J10.1, L1.1
unnamed: C16.2, C17.2, J10.2
unnamed: C5.1, R5.1, R7.2, U1.1 (ADJ)
unnamed: C6.2, R6.2, R8.1, U2.1 (ADJ)
unnamed: C20.1, L3.1, U5.1 (Enable), U6.1 (Vout), U6.2 (Vout), U6.3 (Vout), U6.4 (Vout), U7.1 (Enable)
unnamed: L1.2, R16.1, U5.3 (Vin), U6.9 (Vin), U6.10 (Vin), U7.3 (Vin)
unnamed: C18.1, L2.1, U5.4 (Vout)
unnamed: R15.1, U7.6 (Trim)

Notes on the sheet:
Indicator LEDs
COMPONENT NOTES: R1, R2, R3, (discharges big filter caps) use at least 1W at least Resistors. For all other resistors, use 1/4W. All resistors are metal film, 1% or better tolerance. All screw terminals (J2, J3, J4. J5, J9, J10) are the Phoenix Contact MKDS 1,5 series, 5.08mm pin pitch. Pin headers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
Vref
Short 2&3 for direct ground
+7Vrms
~-25V DC
revision 0.1
~+10V DC
~+25V DC
+18V -18V Clean 3V3 DAC Ref 3V3 Logic 5V Leds 10V Motors
115V/230V Switch
Not on board
13 Jul 2026
RF Shield
SKD ANALOG

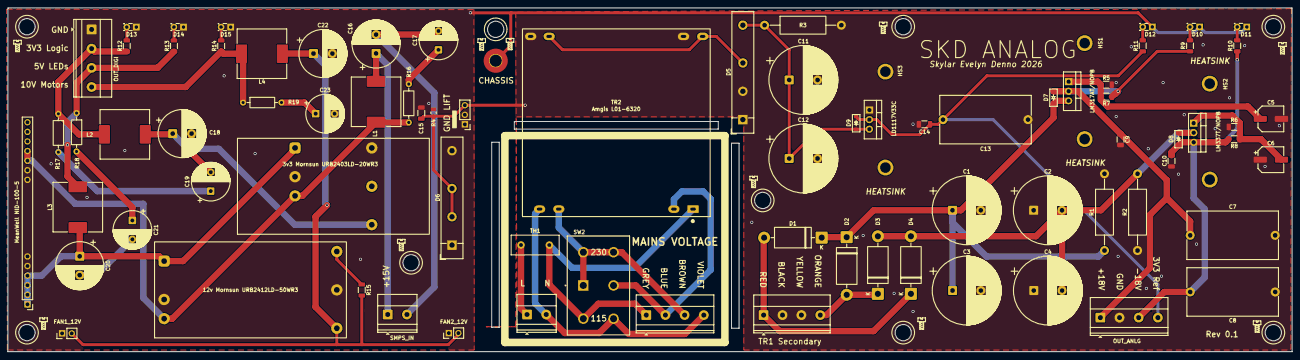
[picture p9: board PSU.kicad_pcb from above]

Board: 4 copper layers, 340.0 x 91.0 mm, 83 parts (0 on the bottom side), 40 nets.

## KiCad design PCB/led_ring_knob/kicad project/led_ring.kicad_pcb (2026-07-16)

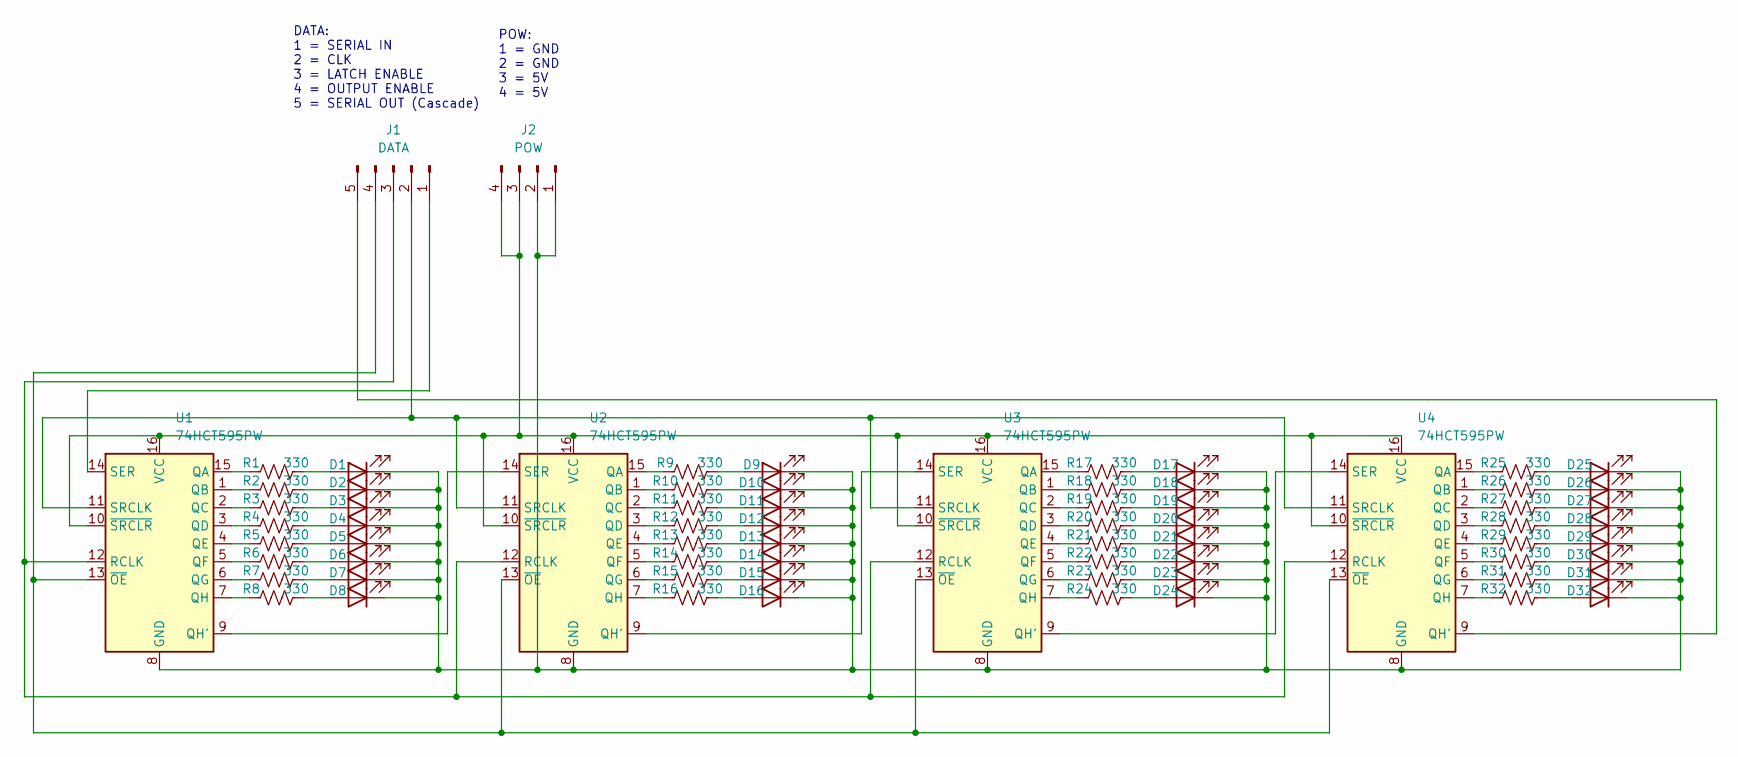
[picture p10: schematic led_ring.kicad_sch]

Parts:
D1, D2, D3, D4, D5, D6, D7, D8, D9, D10, D11, D12, D13, D14, D15, D16, D17, D18, D19, D20, D21, D22, D23, D24, D25, D26, D27, D28, D29, D30, D31, D32: CSP0603AN101-WP30300563001-3T; LED_0201_0603Metric; LCSC C6768746
J1: DATA; PinHeader_1x05_P2.54mm_Vertical; LCSC C5116483
J2: POW; PinHeader_1x04_P2.54mm_Vertical; LCSC C5116483
R1, R2, R3, R4, R5, R6, R7, R8, R9, R10, R11, R12, R13, R14, R15, R16, R17, R18, R19, R20, R21, R22, R23, R24, R25, R26, R27, R28, R29, R30, R31, R32: 330; R_0201_0603Metric
U1, U2, U3, U4: 74HCT595PW; TSSOP-16_4.4x5mm_P0.65mm; LCSC C54411086

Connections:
unnamed: D1.2 (A), R1.2
unnamed: D1.1 (K), D2.1 (K), D3.1 (K), D4.1 (K), D5.1 (K), D6.1 (K), D7.1 (K), D8.1 (K), D9.1 (K), D10.1 (K), D11.1 (K), D12.1 (K), D13.1 (K), D14.1 (K), D15.1 (K), D16.1 (K), D17.1 (K), D18.1 (K), D19.1 (K), D20.1 (K), D21.1 (K), D22.1 (K), D23.1 (K), D24.1 (K), D25.1 (K), D26.1 (K), D27.1 (K), D28.1 (K), D29.1 (K), D30.1 (K), D31.1 (K), D32.1 (K), J2.1, J2.2, U1.8 (GND), U2.8 (GND), U3.8 (GND), U4.8 (GND)
unnamed: D2.2 (A), R2.2
unnamed: D3.2 (A), R3.2
unnamed: D4.2 (A), R4.2
unnamed: D5.2 (A), R5.2
unnamed: D6.2 (A), R6.2
unnamed: D7.2 (A), R7.2
unnamed: D8.2 (A), R8.2
unnamed: D9.2 (A), R9.2
unnamed: D10.2 (A), R10.2
unnamed: D11.2 (A), R11.2
unnamed: D12.2 (A), R12.2
unnamed: D13.2 (A), R13.2
unnamed: D14.2 (A), R14.2
unnamed: D15.2 (A), R15.2
unnamed: D16.2 (A), R16.2
unnamed: D17.2 (A), R17.2
unnamed: D18.2 (A), R18.2
unnamed: D19.2 (A), R19.2
unnamed: D20.2 (A), R20.2
unnamed: D21.2 (A), R21.2
unnamed: D22.2 (A), R22.2
unnamed: D23.2 (A), R23.2
unnamed: D24.2 (A), R24.2
unnamed: D25.2 (A), R25.2
unnamed: D26.2 (A), R26.2
unnamed: D27.2 (A), R27.2
unnamed: D28.2 (A), R28.2
unnamed: D29.2 (A), R29.2
unnamed: D30.2 (A), R30.2
unnamed: D31.2 (A), R31.2
unnamed: D32.2 (A), R32.2
unnamed: J1.1, U1.14 (SER)
unnamed: J1.2, U1.11 (SRCLK), U2.11 (SRCLK), U3.11 (SRCLK), U4.11 (SRCLK)
unnamed: J1.3, U1.12 (RCLK), U2.12 (RCLK), U3.12 (RCLK), U4.12 (RCLK)
unnamed: J1.4, U1.13 (~OE), U2.13 (~OE), U3.13 (~OE), U4.13 (~OE)
unnamed: J1.5, U4.9 (QH')
unnamed: J2.3, J2.4, U1.10 (~SRCLR), U1.16 (VCC), U2.10 (~SRCLR), U2.16 (VCC), U3.10 (~SRCLR), U3.16 (VCC), U4.10 (~SRCLR), U4.16 (VCC)
unnamed: R1.1, U1.15 (QA)
unnamed: R2.1, U1.1 (QB)
unnamed: R3.1, U1.2 (QC)
unnamed: R4.1, U1.3 (QD)
unnamed: R5.1, U1.4 (QE)
unnamed: R6.1, U1.5 (QF)
unnamed: R7.1, U1.6 (QG)
unnamed: U1.9 (QH'), U2.14 (SER)
unnamed: R8.1, U1.7 (QH)
unnamed: R9.1, U2.15 (QA)
unnamed: R10.1, U2.1 (QB)
unnamed: R11.1, U2.2 (QC)
unnamed: R12.1, U2.3 (QD)
unnamed: R13.1, U2.4 (QE)
unnamed: R14.1, U2.5 (QF)
unnamed: R15.1, U2.6 (QG)
unnamed: U2.9 (QH'), U3.14 (SER)
unnamed: R16.1, U2.7 (QH)
unnamed: R17.1, U3.15 (QA)
unnamed: R18.1, U3.1 (QB)
unnamed: R19.1, U3.2 (QC)
unnamed: R20.1, U3.3 (QD)
unnamed: R21.1, U3.4 (QE)
unnamed: R22.1, U3.5 (QF)
unnamed: R23.1, U3.6 (QG)
unnamed: U3.9 (QH'), U4.14 (SER)
unnamed: R24.1, U3.7 (QH)
unnamed: R25.1, U4.15 (QA)
unnamed: R26.1, U4.1 (QB)
unnamed: R27.1, U4.2 (QC)
unnamed: R28.1, U4.3 (QD)
unnamed: R29.1, U4.4 (QE)
unnamed: R30.1, U4.5 (QF)
unnamed: R31.1, U4.6 (QG)
unnamed: R32.1, U4.7 (QH)

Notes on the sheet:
DATA: 1 = SERIAL IN 2 = CLK 3 = LATCH ENABLE 4 = OUTPUT ENABLE 5 = SERIAL OUT (Cascade)
POW: 1 = GND 2 = GND 3 = 5V 4 = 5V

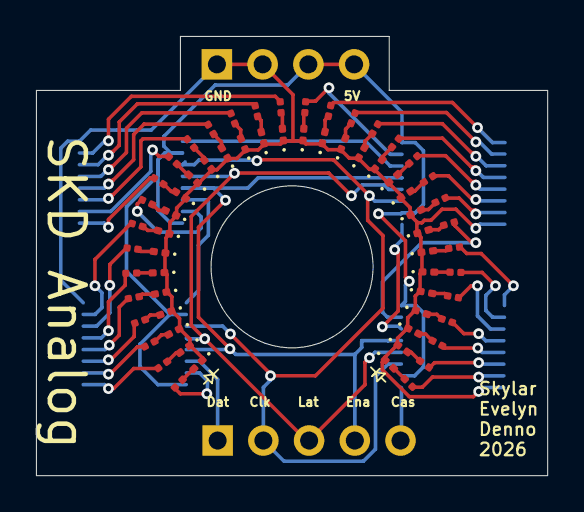
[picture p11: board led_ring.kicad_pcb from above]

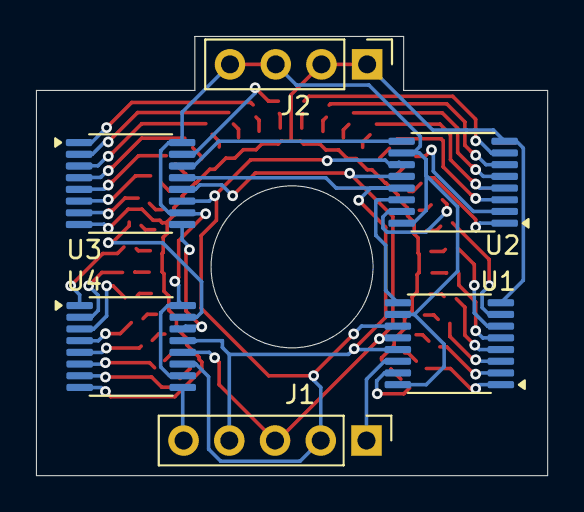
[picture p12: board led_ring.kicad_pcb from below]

Board: 2 copper layers, 28.4 x 24.4 mm, 70 parts (6 on the bottom side), 74 nets.

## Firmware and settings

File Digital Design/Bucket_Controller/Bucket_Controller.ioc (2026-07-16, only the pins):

Mcu.UserName=STM32G474RETx
PA0.GPIO_Label=FADER1_ADC
PA0.Signal=ADC1_IN1
PA1.GPIO_Label=FADER2_ADC
PA1.Signal=ADC1_IN2
PA11.GPIO_Label=FADER3_MOTOR1
PA11.Signal=S_TIM4_CH1
PA12.GPIO_Label=FADER3_MOTOR2
PA12.Signal=S_TIM4_CH2
PA15.GPIO_Label=FADER1_MOTOR1
PA15.Signal=S_TIM2_CH1
PA2.GPIO_Label=FADER3_ADC
PA2.Signal=ADC1_IN3
PA3.GPIO_Label=FADER4_ADC
PA3.Signal=ADC1_IN4
PA4.GPIO_Label=FADER2_MOTOR2
PA4.Signal=S_TIM3_CH2
PA5.GPIO_Label=CV_SPI1_CL
PA5.Signal=SPI1_SCK
PA6.GPIO_Label=FADER2_MOTOR1
PA6.Signal=S_TIM3_CH1
PA7.GPIO_Label=CV_SPI1_MOSI
PA7.Signal=SPI1_MOSI
PB11.GPIO_Label=FADER1_TOUCH
PB11.Signal=GPIO_Input
PB12.GPIO_Label=FADER2_TOUCH
PB12.Signal=GPIO_Input
PB13.GPIO_Label=FADER3_TOUCH
PB13.Signal=GPIO_Input
PB14.GPIO_Label=FADER4_TOUCH
PB14.Signal=GPIO_Input
PB15.GPIO_Label=DISP12_SPI2_MOSI
PB15.Signal=SPI2_MOSI
PB2.GPIO_Label=FADER4_MOTOR1
PB2.Signal=S_TIM5_CH1
PB3.GPIO_Label=FADER1_MOTOR2
PB3.Signal=S_TIM2_CH2
PB5.GPIO_Label=DISP34_SPI3_MOSI
PB5.Signal=SPI3_MOSI
PB7.GPIO_Label=KNOB_I2C1_DA
PB7.Signal=I2C1_SDA
PB8-BOOT0.GPIO_Label=KNOB_I2C1_CL
PB8-BOOT0.Signal=I2C1_SCL
PC0.GPIO_Label=LED_BRIGHT_PWM
PC0.Signal=S_TIM1_CH1
PC1.GPIO_Label=DISP_BRIGHT_PWM
PC1.Signal=S_TIM1_CH2
PC10.GPIO_Label=DISP34_SPI3_CL
PC10.Signal=SPI3_SCK
PC12.GPIO_Label=FADER4_MOTOR2
PC12.Signal=S_TIM5_CH2
PC13.GPIO_Label=LED_CL
PC13.Signal=GPIO_Output
PC2.GPIO_Label=LED_DA
PC2.Signal=GPIO_Output
PC3.GPIO_Label=LED_LATCH
PC3.Signal=GPIO_Output
PC4.GPIO_Label=BTNS_I2C2_CL
PC4.Signal=I2C2_SCL
PC8.GPIO_Label=MASTER_I2C3_CL
PC8.Signal=I2C3_SCL
PC9.GPIO_Label=MASTER_I2C3_DA
PC9.Signal=I2C3_SDA
PF0-OSC_IN.GPIO_Label=BTNS_I2C2_DA
PF0-OSC_IN.Signal=I2C2_SDA
PF1-OSC_OUT.GPIO_Label=DISP12_SPI2_CL
PF1-OSC_OUT.Signal=SPI2_SCK

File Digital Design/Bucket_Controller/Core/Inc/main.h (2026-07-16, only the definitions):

#define LED_CL_Pin GPIO_PIN_13
#define LED_CL_GPIO_Port GPIOC
#define BTNS_I2C2_DA_Pin GPIO_PIN_0
#define BTNS_I2C2_DA_GPIO_Port GPIOF
#define DISP12_SPI2_CL_Pin GPIO_PIN_1
#define DISP12_SPI2_CL_GPIO_Port GPIOF
#define LED_BRIGHT_PWM_Pin GPIO_PIN_0
#define LED_BRIGHT_PWM_GPIO_Port GPIOC
#define DISP_BRIGHT_PWM_Pin GPIO_PIN_1
#define DISP_BRIGHT_PWM_GPIO_Port GPIOC
#define LED_DA_Pin GPIO_PIN_2
#define LED_DA_GPIO_Port GPIOC
#define LED_LATCH_Pin GPIO_PIN_3
#define LED_LATCH_GPIO_Port GPIOC
#define FADER1_ADC_Pin GPIO_PIN_0
#define FADER1_ADC_GPIO_Port GPIOA
#define FADER2_ADC_Pin GPIO_PIN_1
#define FADER2_ADC_GPIO_Port GPIOA
#define FADER3_ADC_Pin GPIO_PIN_2
#define FADER3_ADC_GPIO_Port GPIOA
#define FADER4_ADC_Pin GPIO_PIN_3
#define FADER4_ADC_GPIO_Port GPIOA
#define FADER2_MOTOR2_Pin GPIO_PIN_4
#define FADER2_MOTOR2_GPIO_Port GPIOA
#define CV_SPI1_CL_Pin GPIO_PIN_5
#define CV_SPI1_CL_GPIO_Port GPIOA
#define FADER2_MOTOR1_Pin GPIO_PIN_6
#define FADER2_MOTOR1_GPIO_Port GPIOA
#define CV_SPI1_MOSI_Pin GPIO_PIN_7
#define CV_SPI1_MOSI_GPIO_Port GPIOA
#define BTNS_I2C2_CL_Pin GPIO_PIN_4
#define BTNS_I2C2_CL_GPIO_Port GPIOC
#define FADER4_MOTOR1_Pin GPIO_PIN_2
#define FADER4_MOTOR1_GPIO_Port GPIOB
#define FADER1_TOUCH_Pin GPIO_PIN_11
#define FADER1_TOUCH_GPIO_Port GPIOB
#define FADER2_TOUCH_Pin GPIO_PIN_12
#define FADER2_TOUCH_GPIO_Port GPIOB
#define FADER3_TOUCH_Pin GPIO_PIN_13
#define FADER3_TOUCH_GPIO_Port GPIOB
#define FADER4_TOUCH_Pin GPIO_PIN_14
#define FADER4_TOUCH_GPIO_Port GPIOB
#define DISP12_SPI2_MOSI_Pin GPIO_PIN_15
#define DISP12_SPI2_MOSI_GPIO_Port GPIOB
#define MASTER_I2C3_CL_Pin GPIO_PIN_8
#define MASTER_I2C3_CL_GPIO_Port GPIOC
#define MASTER_I2C3_DA_Pin GPIO_PIN_9
#define MASTER_I2C3_DA_GPIO_Port GPIOC
#define FADER3_MOTOR1_Pin GPIO_PIN_11
#define FADER3_MOTOR1_GPIO_Port GPIOA
#define FADER3_MOTOR2_Pin GPIO_PIN_12
#define FADER3_MOTOR2_GPIO_Port GPIOA
#define FADER1_MOTOR1_Pin GPIO_PIN_15
#define FADER1_MOTOR1_GPIO_Port GPIOA
#define DISP34_SPI3_CL_Pin GPIO_PIN_10
#define DISP34_SPI3_CL_GPIO_Port GPIOC
#define FADER4_MOTOR2_Pin GPIO_PIN_12
#define FADER4_MOTOR2_GPIO_Port GPIOC
#define FADER1_MOTOR2_Pin GPIO_PIN_3
#define FADER1_MOTOR2_GPIO_Port GPIOB
#define DISP34_SPI3_MOSI_Pin GPIO_PIN_5
#define DISP34_SPI3_MOSI_GPIO_Port GPIOB
#define KNOB_I2C1_DA_Pin GPIO_PIN_7
#define KNOB_I2C1_DA_GPIO_Port GPIOB
#define KNOB_I2C1_CL_Pin GPIO_PIN_8
#define KNOB_I2C1_CL_GPIO_Port GPIOB

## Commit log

2026-07-16 init commit
    [PSU.kicad_pcb, PSU.kicad_sch, Pin Assigments.xlsx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]
2026-07-17 cleanup + prep for pcb design
    [PSU.kicad_pcb, PSU.kicad_sch]
2026-07-17 pcb rev 0
    [PSU.kicad_pcb, PSU.kicad_sch]
2026-07-18 rev 0.1 4 layer
    [PSU.kicad_pcb, designators.csv, positions.csv]
2026-07-19 quick update / fix
    [PSU.kicad_pcb, PSU.kicad_sch]

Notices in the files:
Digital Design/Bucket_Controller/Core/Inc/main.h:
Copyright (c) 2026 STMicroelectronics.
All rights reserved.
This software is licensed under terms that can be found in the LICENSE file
